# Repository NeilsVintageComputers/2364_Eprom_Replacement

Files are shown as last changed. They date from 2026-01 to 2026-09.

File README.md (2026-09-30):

# 2364_Eprom_Replacement

These adapters mount a smd eeprom, AT28C64B, on a pcb that fits and plugs into the 24-pin 2364 footprint. It is much narrower than all the other adapters I have seen (only as wide as the 2364 socket) which allows them to fit side by side in closely spaced sockets like in the IBM 5150.

The programming adapters that are required to program the eeprom board have a 28 or 32 pin header to plug into a eprom programmer.

The only difference in the two versions is the number of pins on the programming adapter, one has 32 pins which is the number of pins on the smd version of the AT28C64B, the other has 28 pins which is the number of pins on the dil version of the AT28C64.  
Choose which ever version will suit your eprom programmer, if the programmer supports the 32-pin SMD version build the 32-pin adapter or if it only supports the 28-pin throughhole version then build the 28-pin adapter.

The jumpers on the rear should be OPEN when programming the device, CLOSED for use in normal read mode.
The "A" and "B" (Which is NOT a jumper) on the eeprom board should be connected to "A" and "B" on the programmer board.

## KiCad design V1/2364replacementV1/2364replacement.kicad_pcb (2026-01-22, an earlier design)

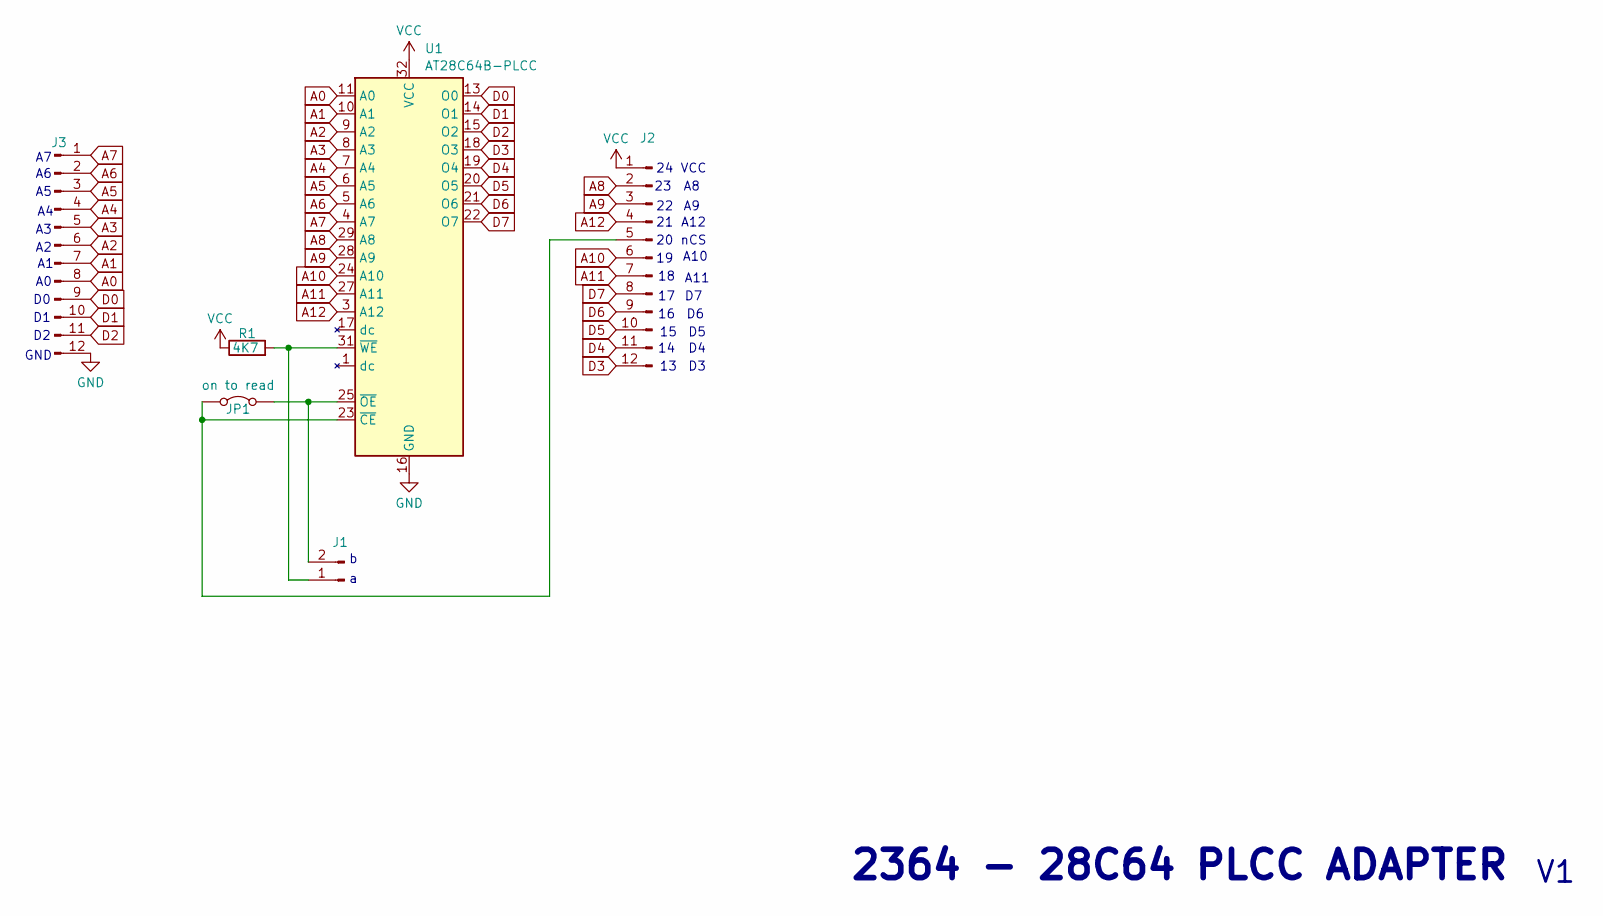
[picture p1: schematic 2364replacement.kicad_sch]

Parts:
J1: Conn_01x02_Pin; PinHeader_1x02_P2.54mm_Vertical
J2, J3: Conn_01x12_Pin; PinHeader_1x12_P2.54mm_Vertical
JP1: on to read; PinHeader_1x02_P2.54mm_Vertical
R1: 4K7; R_Axial_DIN0207_L6.3mm_D2.5mm_P10.16mm_Horizontal
U1: AT28C64B-PLCC; PLCC-32_11.4x14.0mm_P1.27mm

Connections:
A0: J3.8, U1.11 (A0)
A1: J3.7, U1.10 (A1)
A2: J3.6, U1.9 (A2)
A3: J3.5, U1.8 (A3)
A4: J3.4, U1.7 (A4)
A5: J3.3, U1.6 (A5)
A6: J3.2, U1.5 (A6)
A7: J3.1, U1.4 (A7)
A8: J2.2, U1.29 (A8)
A9: J2.3, U1.28 (A9)
A10: J2.6, U1.24 (A10)
A11: J2.7, U1.27 (A11)
A12: J2.4, U1.3 (A12)
D0: J3.9, U1.13 (O0)
D1: J3.10, U1.14 (O1)
D2: J3.11, U1.15 (O2)
D3: J2.12, U1.18 (O3)
D4: J2.11, U1.19 (O4)
D5: J2.10, U1.20 (O5)
D6: J2.9, U1.21 (O6)
D7: J2.8, U1.22 (O7)
GND: J3.12, U1.16 (GND)
unnamed: J2.5, JP1.1 (A), U1.23 (~CE)
unnamed: J1.1, R1.2, U1.31 (~WE)
unnamed: J1.2, JP1.2 (B), U1.25 (~OE)
VCC: J2.1, R1.1, U1.32 (VCC)

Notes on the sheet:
VCC
A12
nCS
A10
2364 - 28C64 PLCC ADAPTER
A11
GND

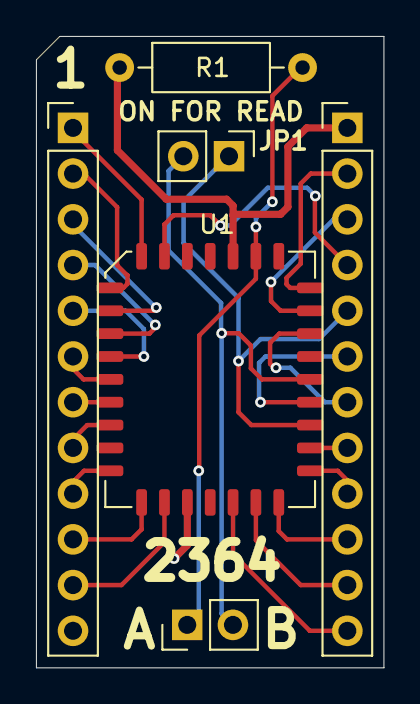
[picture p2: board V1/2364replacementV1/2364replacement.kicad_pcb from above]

Board: 2 copper layers, 19.3 x 35.1 mm, 6 parts (0 on the bottom side), 26 nets.

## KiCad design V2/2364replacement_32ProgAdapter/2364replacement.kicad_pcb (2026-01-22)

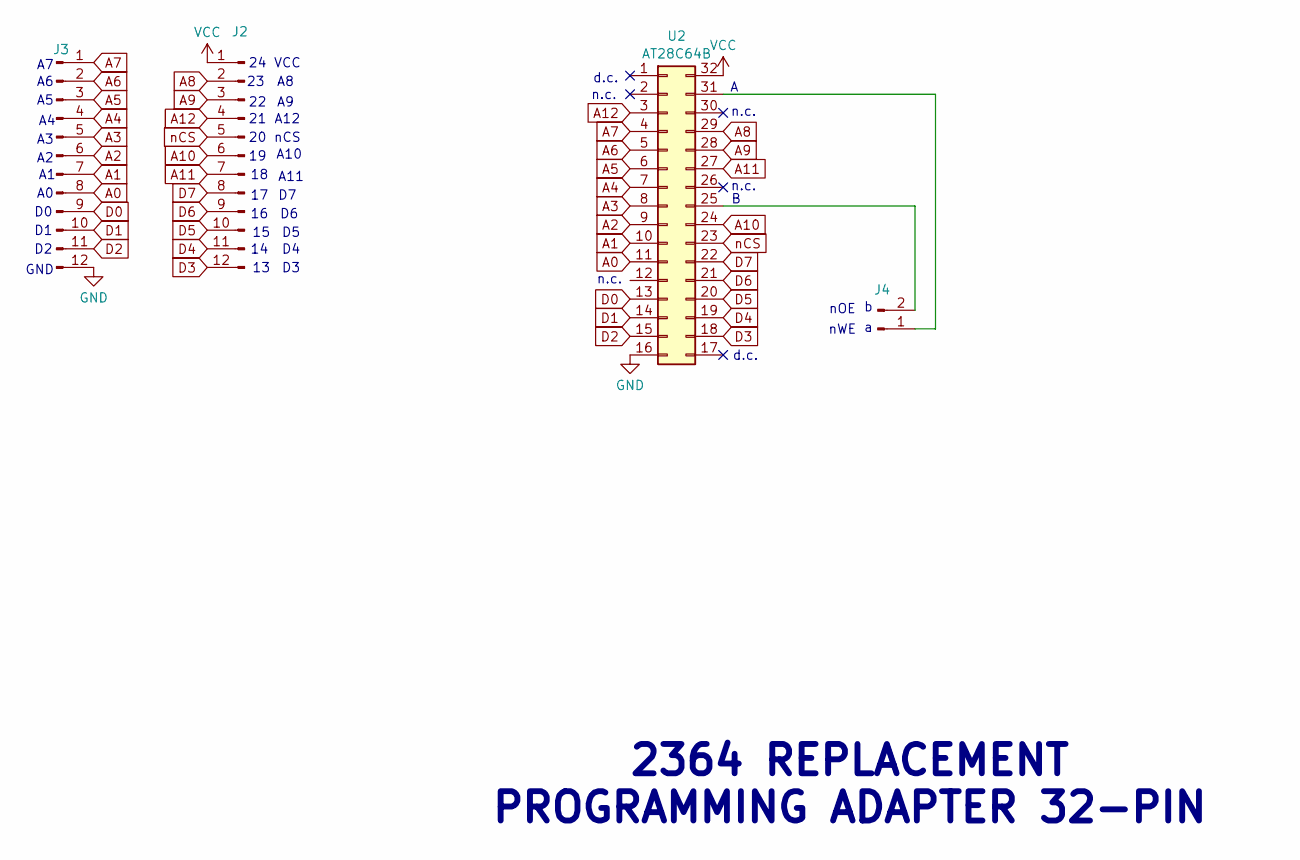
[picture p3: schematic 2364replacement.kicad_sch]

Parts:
J2, J3: Conn_01x12_Pin; PinHeader_1x12_P2.54mm_Vertical
J4: Conn_01x02_Pin; PinHeader_1x02_P2.54mm_Vertical
U2: AT28C64B; DIP-32_W15.24mm_LongPads

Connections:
A0: J3.8, U2.11
A1: J3.7, U2.10
A2: J3.6, U2.9
A3: J3.5, U2.8
A4: J3.4, U2.7
A5: J3.3, U2.6
A6: J3.2, U2.5
A7: J3.1, U2.4
A8: J2.2, U2.29
A9: J2.3, U2.28
A10: J2.6, U2.24
A11: J2.7, U2.27
A12: J2.4, U2.3
D0: J3.9, U2.13
D1: J3.10, U2.14
D2: J3.11, U2.15
D3: J2.12, U2.18
D4: J2.11, U2.19
D5: J2.10, U2.20
D6: J2.9, U2.21
D7: J2.8, U2.22
GND: J3.12, U2.16
unnamed: J4.1, U2.31
unnamed: J4.2, U2.25
VCC: J2.1, U2.32
nCS: J2.5, U2.23

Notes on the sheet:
VCC
n.c.
nOE
A12
nWE
nCS
d.c.
2364 REPLACEMENT PROGRAMMING ADAPTER 32-PIN
A10
A11
GND

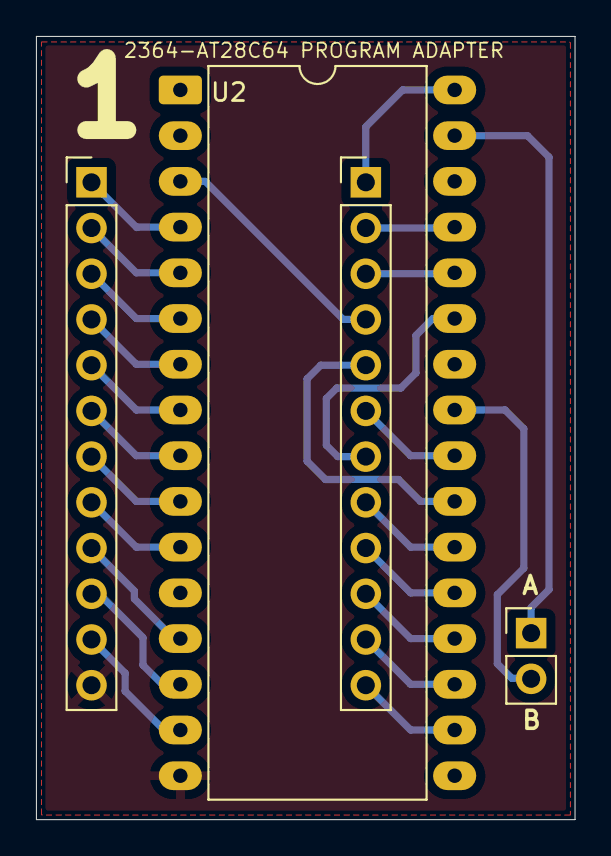
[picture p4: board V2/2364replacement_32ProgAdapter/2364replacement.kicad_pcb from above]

Board: 2 copper layers, 29.9 x 43.5 mm, 4 parts (0 on the bottom side), 26 nets.

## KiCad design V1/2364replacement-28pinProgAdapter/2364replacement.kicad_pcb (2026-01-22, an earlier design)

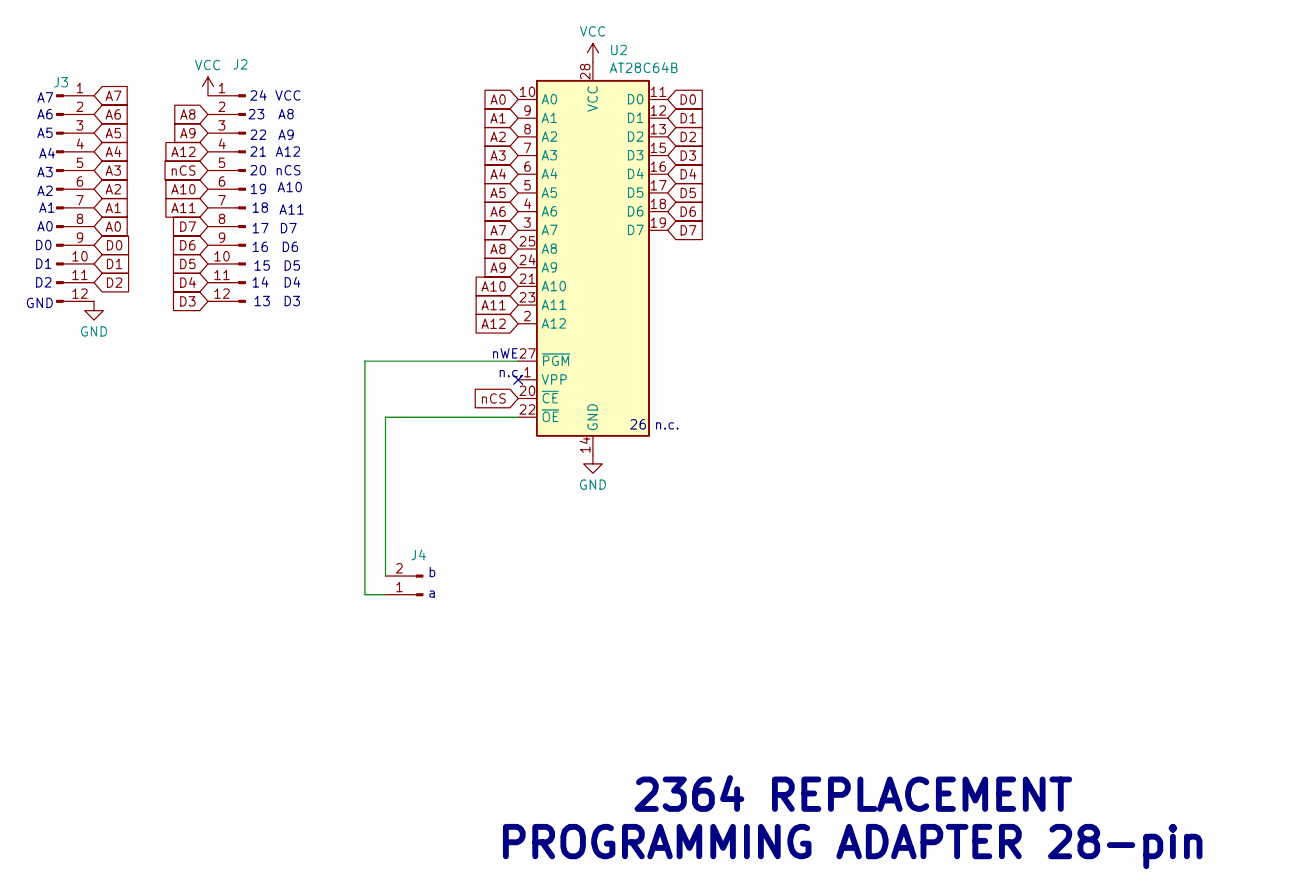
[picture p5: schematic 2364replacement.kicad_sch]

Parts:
J2, J3: Conn_01x12_Pin; PinHeader_1x12_P2.54mm_Vertical
J4: Conn_01x02_Pin; PinHeader_1x02_P2.54mm_Vertical
U2: AT28C64B; DIP-28_W15.24mm

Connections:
A0: J3.8, U2.10 (A0)
A1: J3.7, U2.9 (A1)
A2: J3.6, U2.8 (A2)
A3: J3.5, U2.7 (A3)
A4: J3.4, U2.6 (A4)
A5: J3.3, U2.5 (A5)
A6: J3.2, U2.4 (A6)
A7: J3.1, U2.3 (A7)
A8: J2.2, U2.25 (A8)
A9: J2.3, U2.24 (A9)
A10: J2.6, U2.21 (A10)
A11: J2.7, U2.23 (A11)
A12: J2.4, U2.2 (A12)
D0: J3.9, U2.11 (D0)
D1: J3.10, U2.12 (D1)
D2: J3.11, U2.13 (D2)
D3: J2.12, U2.15 (D3)
D4: J2.11, U2.16 (D4)
D5: J2.10, U2.17 (D5)
D6: J2.9, U2.18 (D6)
D7: J2.8, U2.19 (D7)
GND: J3.12, U2.14 (GND)
unnamed: J4.1, U2.27 (~PGM)
unnamed: J4.2, U2.22 (~OE)
VCC: J2.1, U2.28 (VCC)
nCS: J2.5, U2.20 (~CE)

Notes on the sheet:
VCC
n.c.
A12
nWE
nCS
26 n.c.
2364 REPLACEMENT PROGRAMMING ADAPTER 28-pin
A10
A11
GND

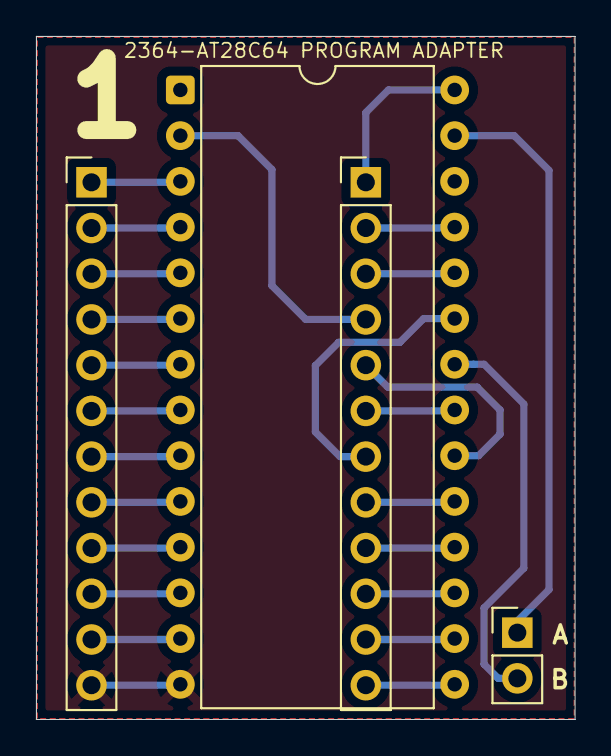
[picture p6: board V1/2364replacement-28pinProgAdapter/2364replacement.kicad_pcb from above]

Board: 2 copper layers, 29.9 x 37.9 mm, 4 parts (0 on the bottom side), 26 nets.
